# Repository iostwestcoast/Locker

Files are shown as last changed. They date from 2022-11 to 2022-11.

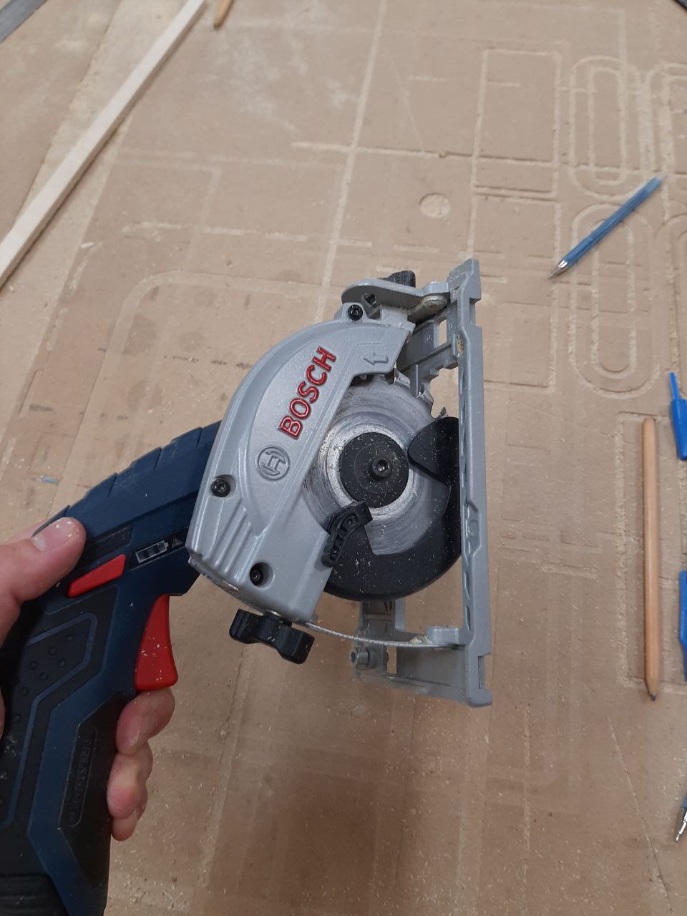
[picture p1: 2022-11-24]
Photos/photo_2022-11-24_02-31-51.jpg

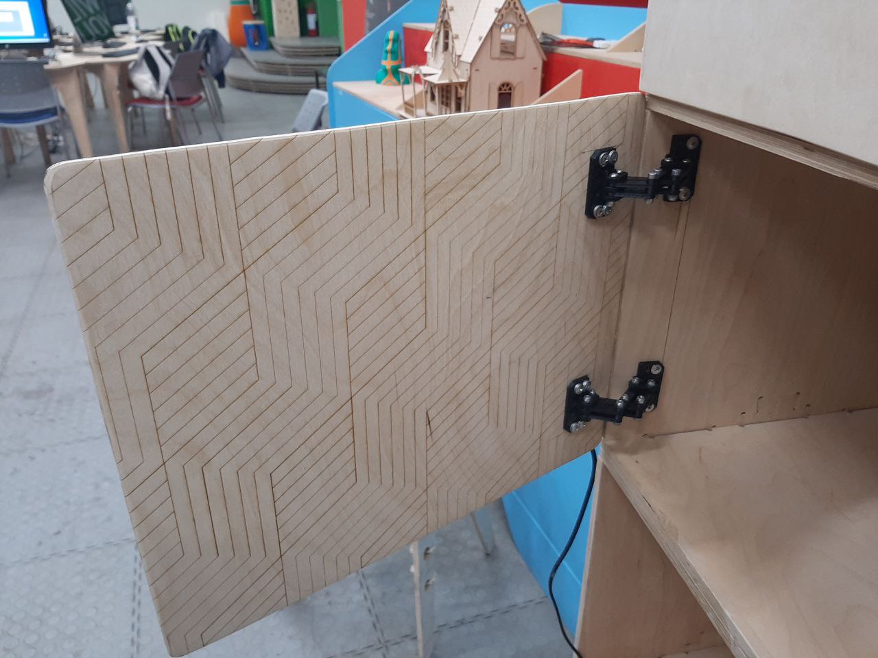
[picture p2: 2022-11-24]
Photos/photo_2022-11-24_02-32-20.jpg

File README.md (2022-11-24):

# Locker
Creating a locker door from plywood and fabricating with the assembly of the necessary equipment

## Production process

Marking and cutting out a plywood door 



Door assembly printing



## The result

Interior view



Exterior view 



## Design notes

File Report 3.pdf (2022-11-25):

Иост Евгений МТМО 22–3

### Введение в проект

Целью данной работы являлось создание дверцы шкафчика, с учетом изготовления

петлей и электронного запирающего механизма, срабатывающего при помощи RFID метки

через датчик на управляющей плате.

### Изготовление деталей

Изначально был передвижной шкаф с 8ю отсеками. Для начала были сняты

размеры проема для дверцы 445 мм на 355 мм. Было решено, что дверца будет сделана в

нахлест на рамки шкафчика. В качестве материала была выбрана фанера 6 мм, так как это

удобный в обработке и эксплуатации материал. Далее была произведена разметка на листе

фанеры и с помощью ручной мини циркулярной пилы была вырезана дверца.

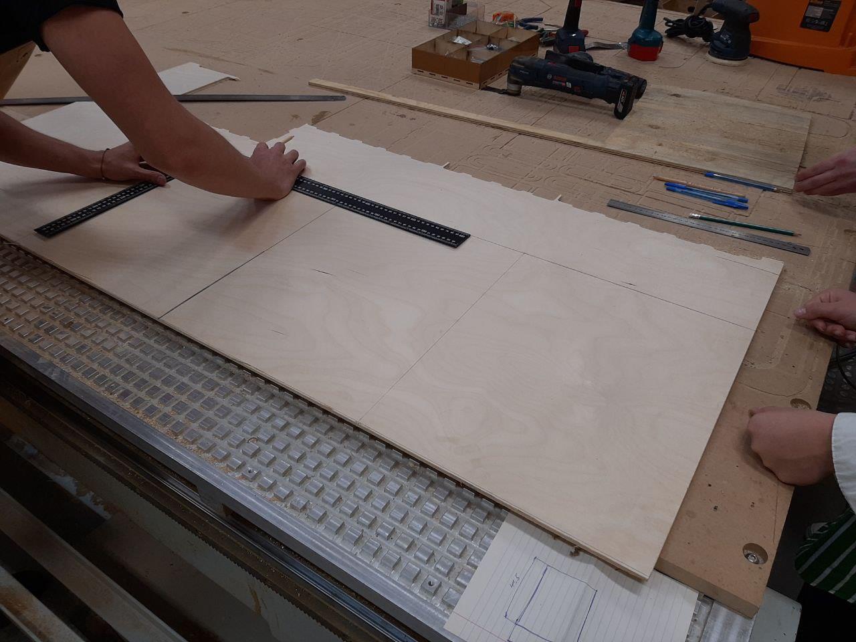
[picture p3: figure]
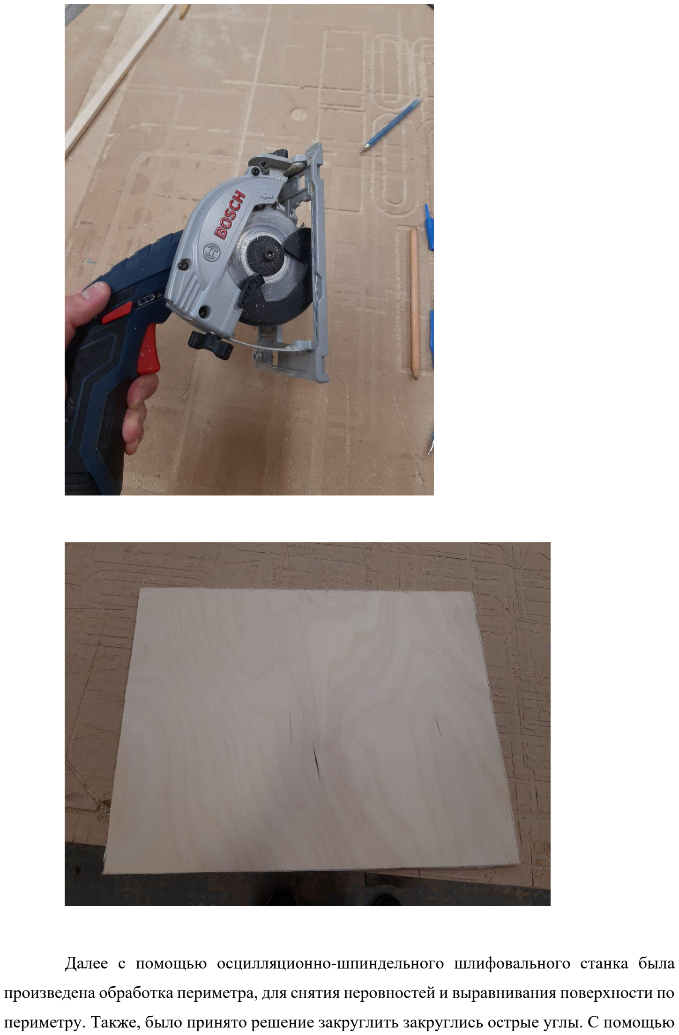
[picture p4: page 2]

Далее с помощью осцилляционно-шпиндельного шлифовального станка была

произведена обработка периметра, для снятия неровностей и выравнивания поверхности по

периметру. Также, было принято решение закруглить закруглись острые углы. С помощью

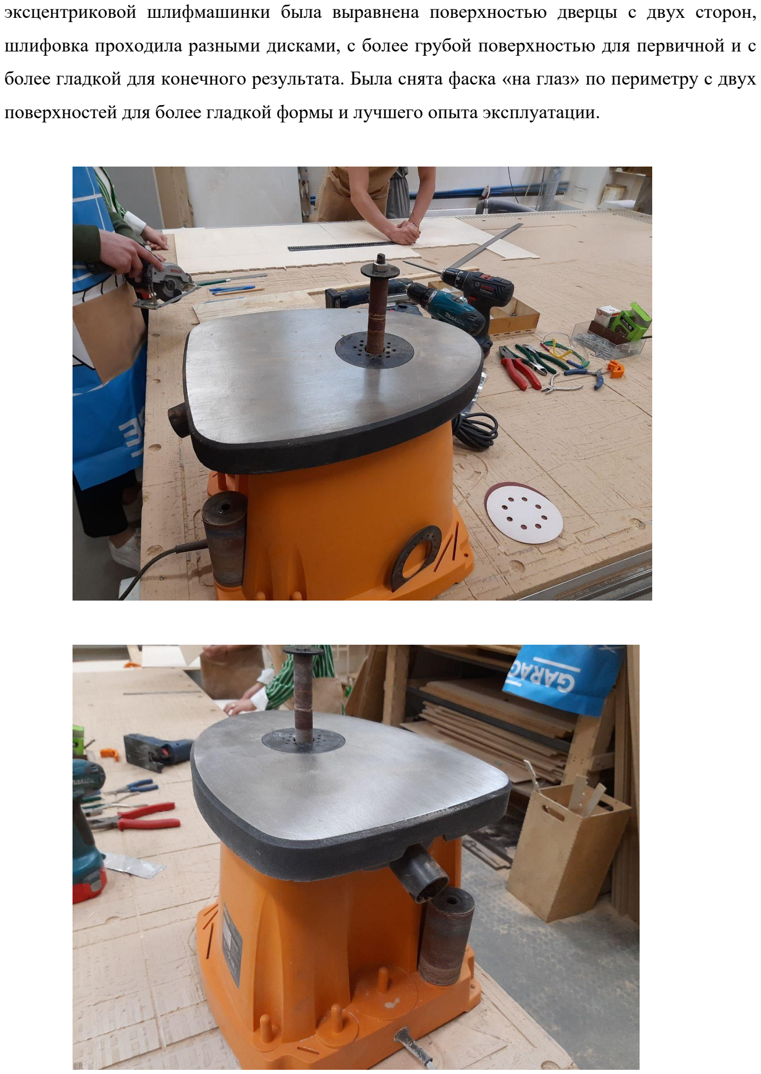
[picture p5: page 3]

эксцентриковой шлифмашинки была выравнена поверхностью дверцы с двух сторон,

шлифовка проходила разными дисками, с более грубой поверхностью для первичной и с

более гладкой для конечного результата. Была снята фаска «на глаз» по периметру с двух

поверхностей для более гладкой формы и лучшего опыта эксплуатации.

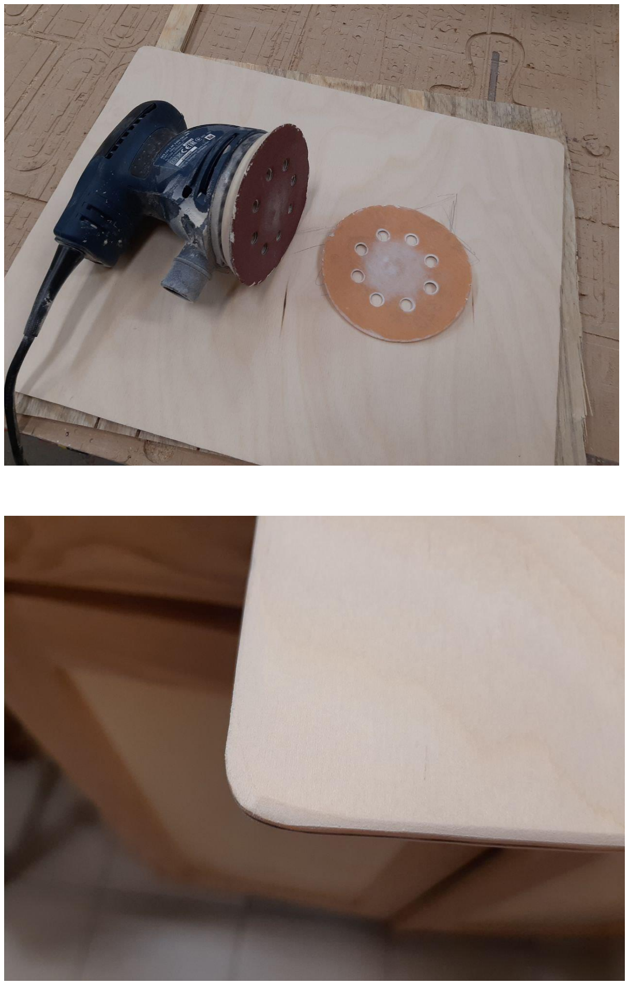
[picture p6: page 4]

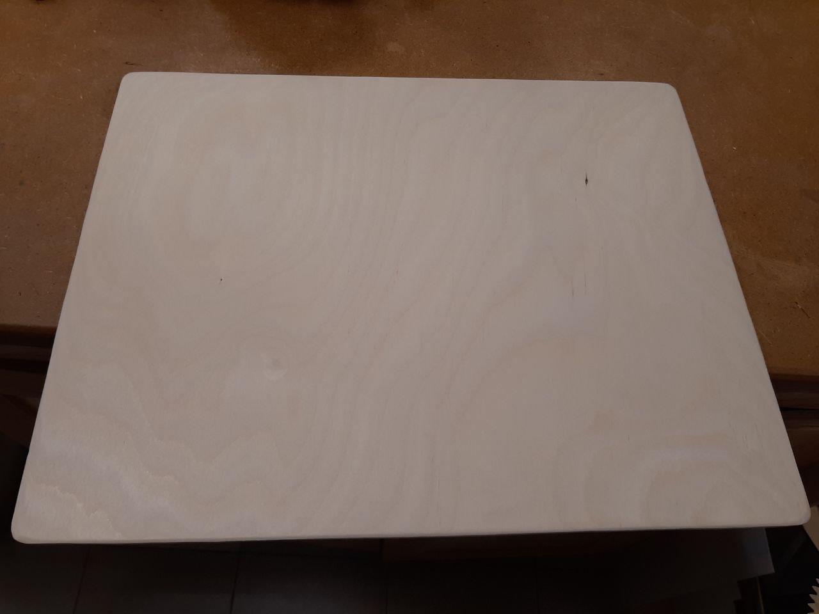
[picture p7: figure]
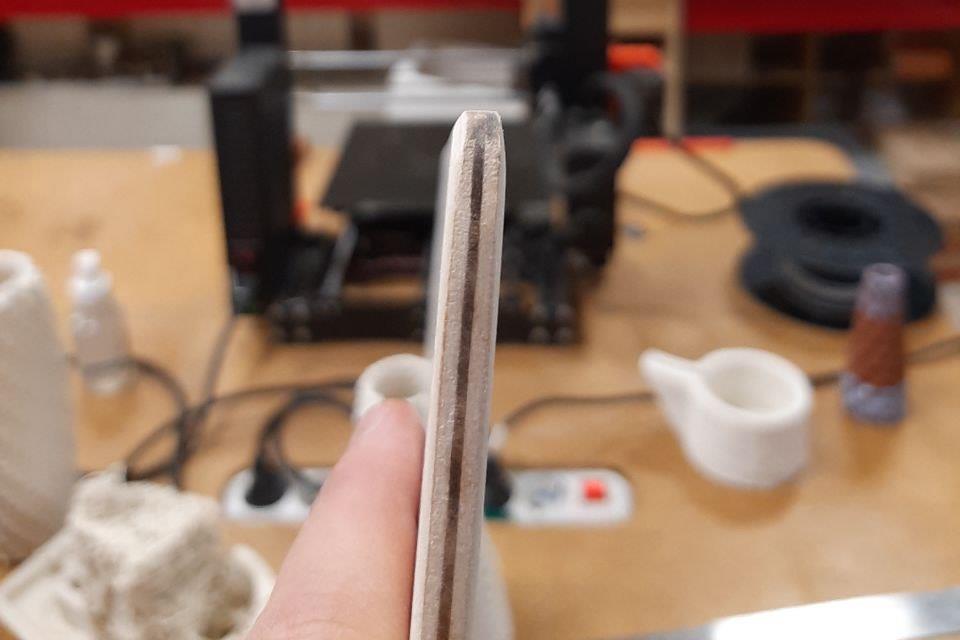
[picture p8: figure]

С обработкой поверхности было закончено. На следующем этапе работы был

выбран общий дизайн и расположение на дверце номера локера и именных данных. Для

начала были подобраны и протестированы настройки в программе для нанесения

гравировки на дверце. Была сделана гравировка номера и имени. Далее на листе плотной

бумаги был вырезан на лазерном станке трафарет цифры. Изначально гравировка номера

была сделана для точного расположения трафарета. Трафарет был закреплен

двухсторонним скотчем для лучшего прилегания. Вся дверца была закрыта листами, чтобы

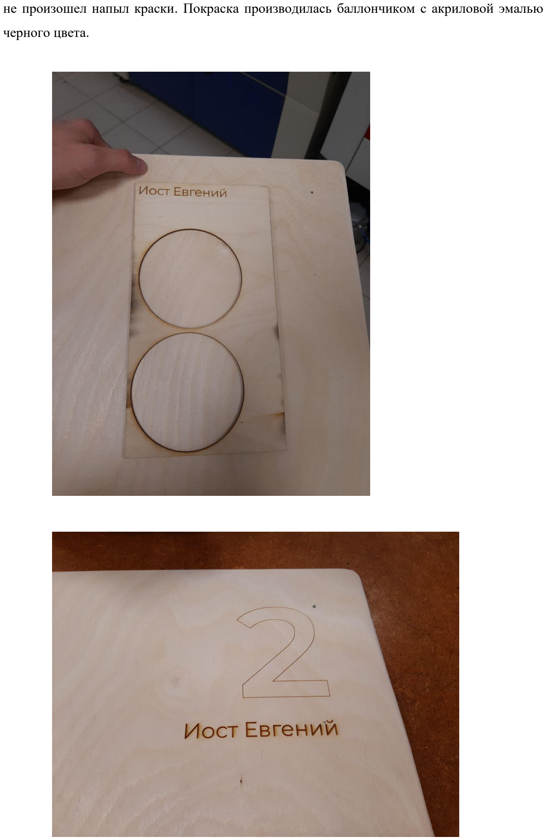
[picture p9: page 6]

не произошел напыл краски. Покраска производилась баллончиком с акриловой эмалью

черного цвета.

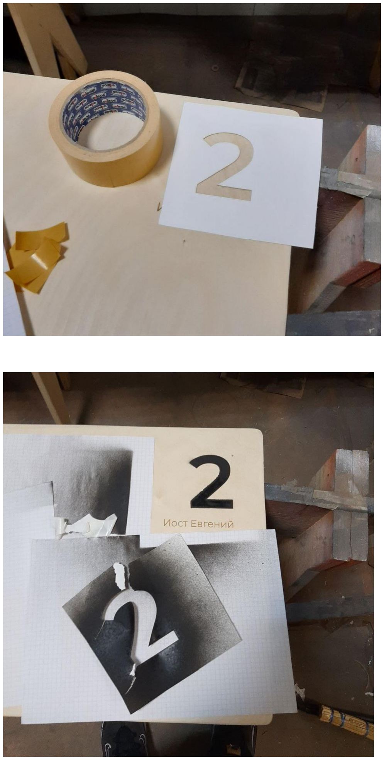
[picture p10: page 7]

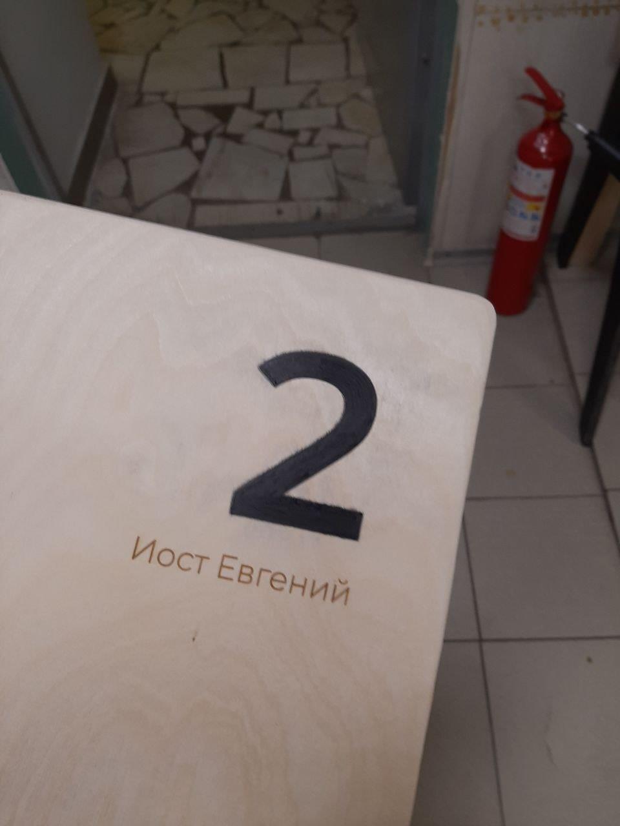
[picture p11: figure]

Что качается дизайна задней поверхности, было принято решение сделать

гравировку. Была найдена картинка в векторном изображении и была произведена

гравировка на весь периметр задней поверхности.

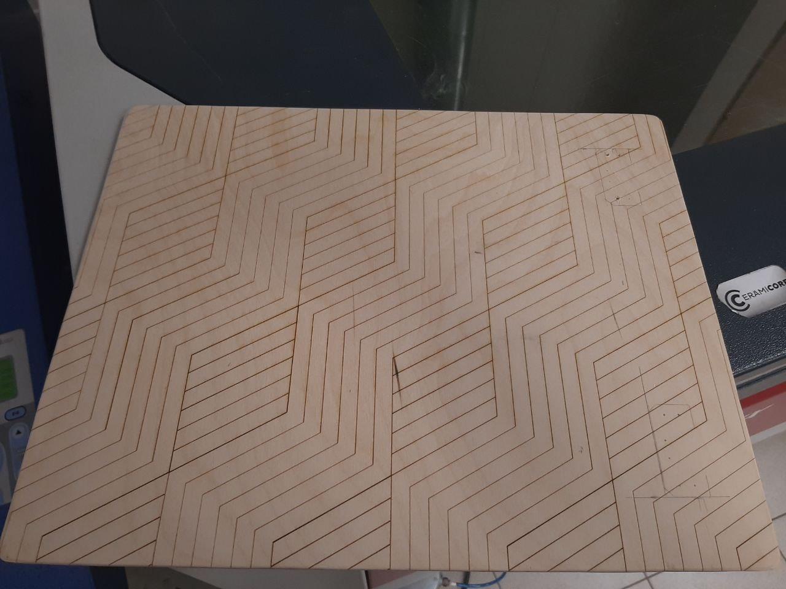
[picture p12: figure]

На следующем этапе работы было изготовление петель. Трудность была в том, что

нужны были петли с выносом в 1 и более см, так как дверца должна располагаться внахлест.

Изготовление было принято решение производить при помощи 3д принтера по пластику.

Изначально была найдена модель петель, которые печаталась бы сразу в сборе, но сколько

разных пластиков или настроек печати не было бы поменяно, деталь всегда получалась с

дефектами: заблокированные подвижные элементы, низкая прочность детали, сильные

люфты в соединениях. Далее была найдена более совершенная модель петель, но они были

сборочные с использованием болтов м6. Они были напечатаны и собраны во едино.

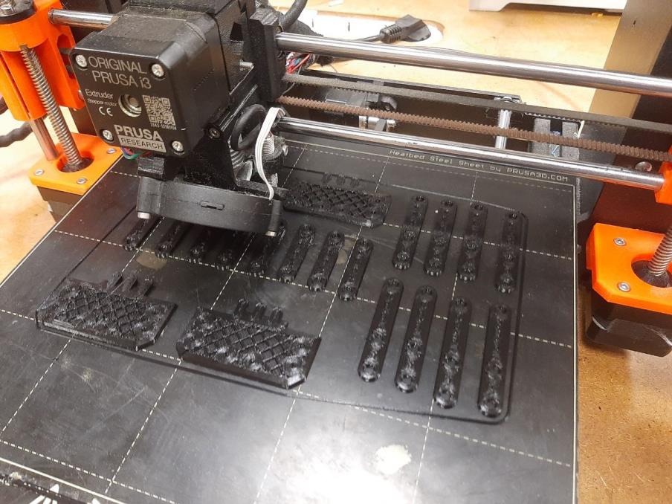
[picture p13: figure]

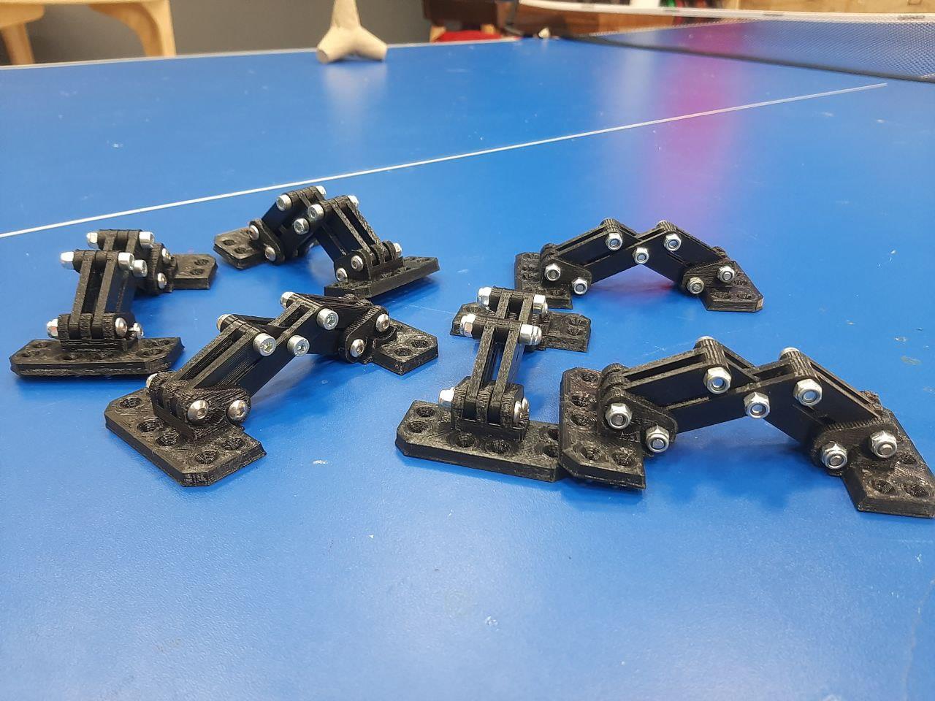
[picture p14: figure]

Поскольку локер с электронным запирающим механизмом, а в качестве его был

выбран соленоид, для его фиксации и работоспособности механизма было распечатано

дополнительно навесное оборудование: крепление соленоида, язычек, паз для язычка и

фиксатор рабочей втулки соленоида. Из-за того, что данные компоненты тоже были

напечатаны, они нуждались в доработке, отрезались выступающие, дефектные части

первых слоев печати, производилась шлифовка рабочих скользящих поверхностей до

более-менее гладкого состояния. Таже из-за несовершенства печати, рассверливались

отверстия для крепления петель, крепления и паза на дверцу шкафчика. Далее была сделана

сборка компонентов, крепление прикручивалось короткими болтами м3, цианоакрилатным

клеем приклеен фиксатор втулки для лучшей фиксации, язычек приклеен на клеевой

пистолет. Также на данным этапе было измерено расстояние с запасом от соленоида до

основного блока управления всеми локерами с учетом кабель менеджмента для напайки

проводов к соленоиду. Дале провода были припаяны, а места спайки заизолированы

термоусадкой, провода закручивались для лучшего менеджмента и эстетичного вида.

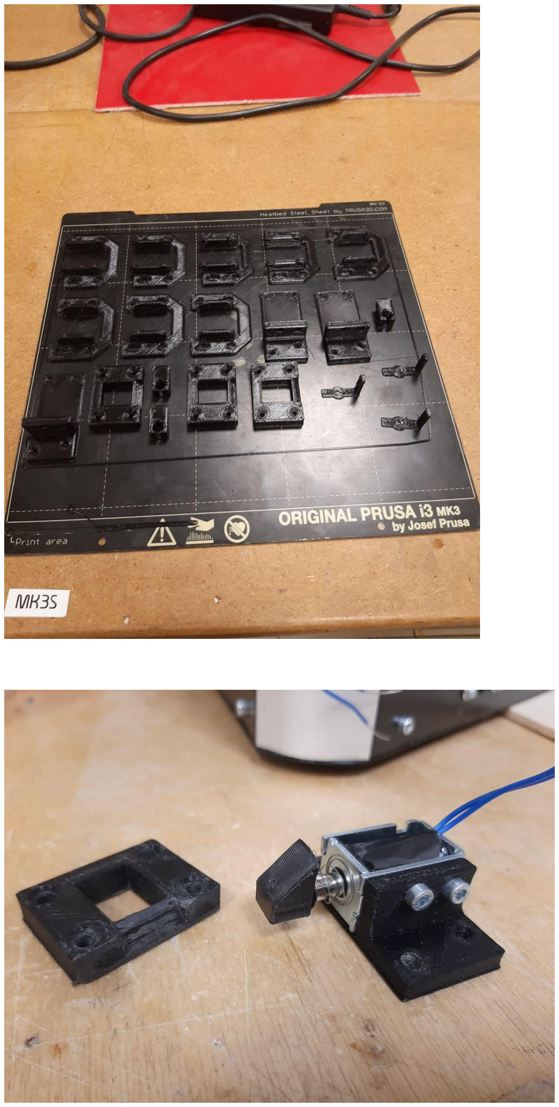
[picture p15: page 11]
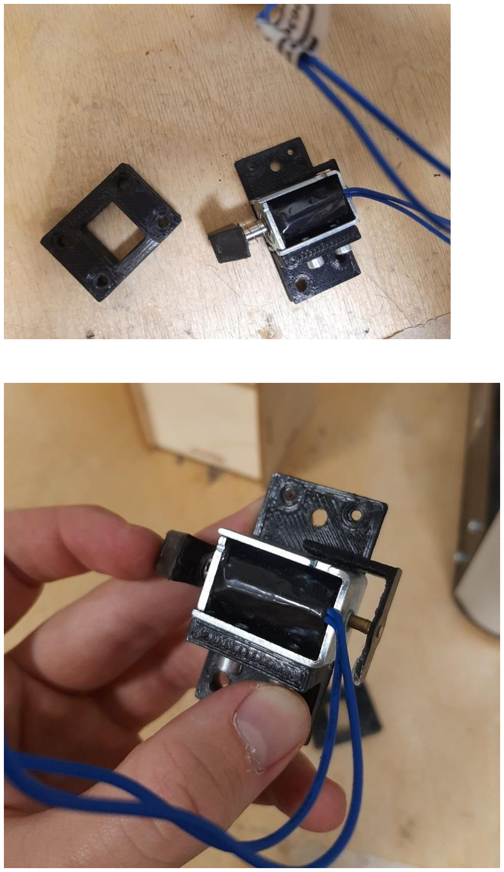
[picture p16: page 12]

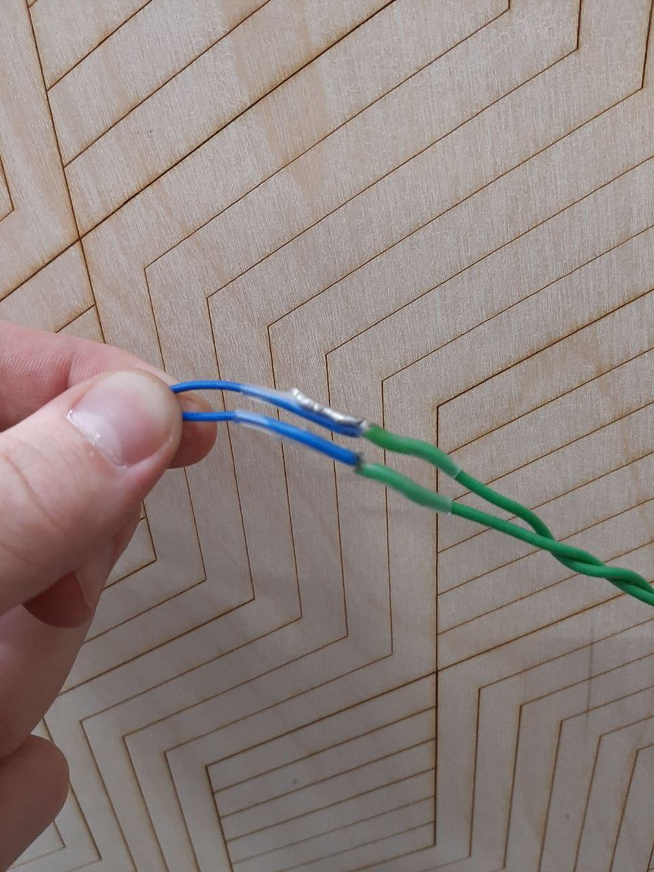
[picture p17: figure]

Механизм локера будет отрываться с помощью RFID метки, которую мы подносим

к датчику-считывателю в основном блоке управления. Для метки было принято решение

сделать брелок для ключей, а метка имеется на самоклеящийся основе. Для проекта было

найдено большое разнообразие брелков. Выбрав лучший вариант, модель была подогнана

по размерам к метке и брелок был напечатан на принтере в черном цвете, далее вклеена

метка.

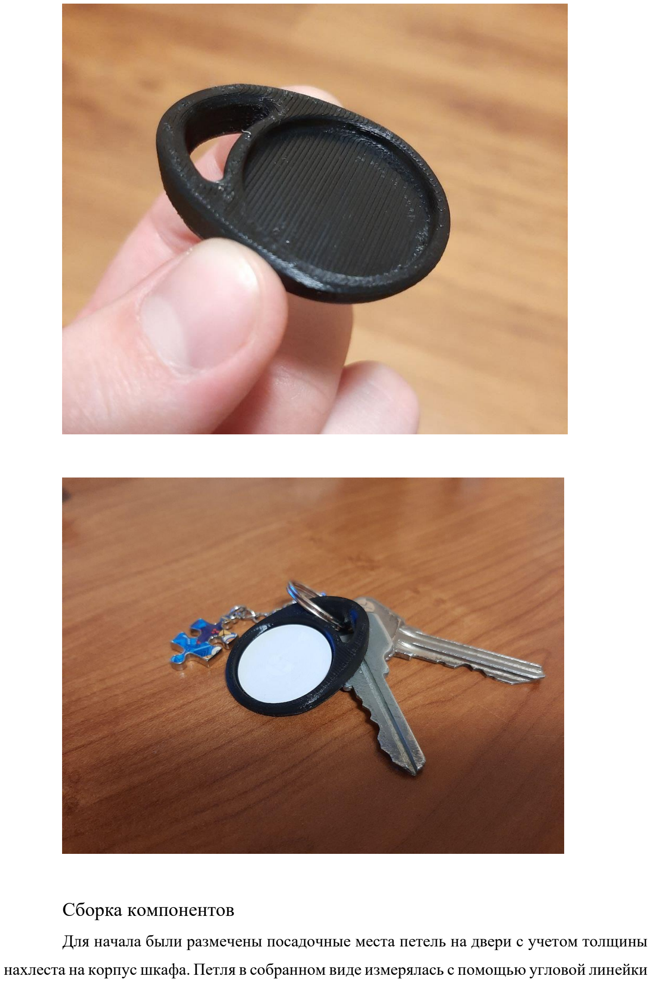
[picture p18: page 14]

### Сборка компонентов

Для начала были размечены посадочные места петель на двери с учетом толщины

нахлеста на корпус шкафа. Петля в собранном виде измерялась с помощью угловой линейки в закрытом виде, отступ от края дверцы составил 6 см, а от края шкафа 5 см. Так как фанера

толщиной всего 6 мм, а необходимых саморезов не было в наличии для работы над

проектом, пришлось опытным путем и методом проб и замеров подбирать количество шайб

для проставки между шляпкой прессшайбы, также пришлось укорачивать острый

наконечник пресшайбы кусачками. Когда петли были прикручены к двери, произвелась

разметка на шкафу. Далее прикручена дверца. Косательно запирающего механизма также

была произведена разметка и с помощью проставок шайбами весь механизм был

прикручен, включая паз для языка. Кабель менеджмент был сделан с помощью медельного

степлера с короткими скобами. Также кабель питания соленоида был протянут и подключен

в плату управления на нужную позицию по номеру локера.

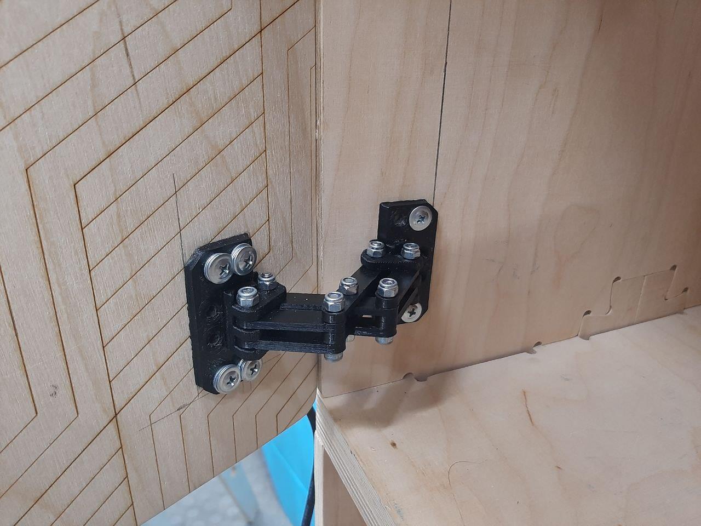
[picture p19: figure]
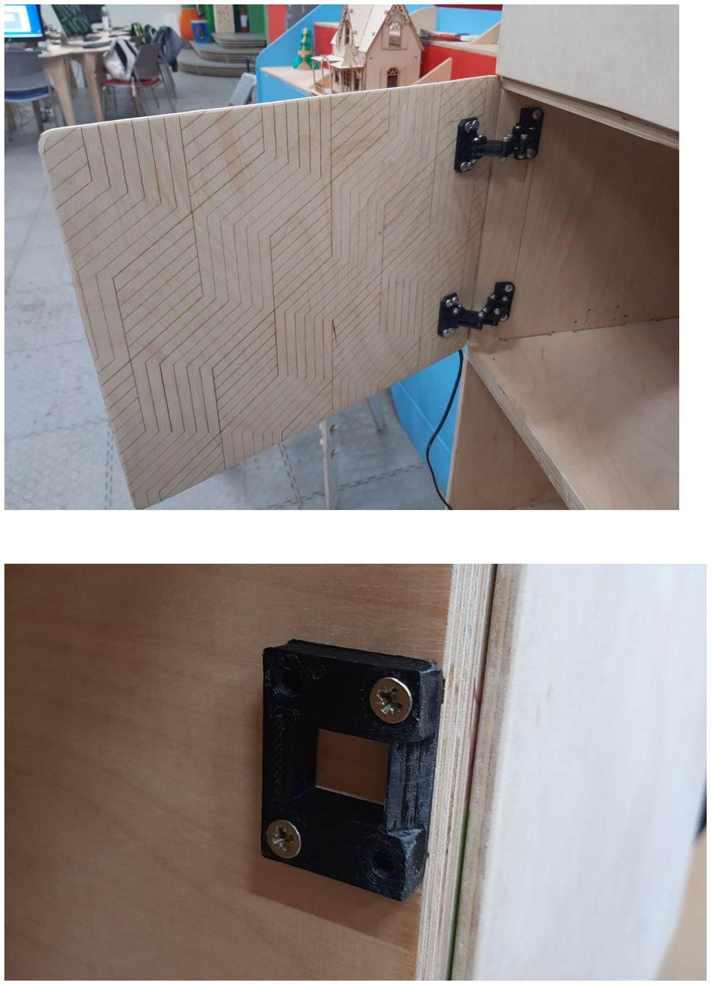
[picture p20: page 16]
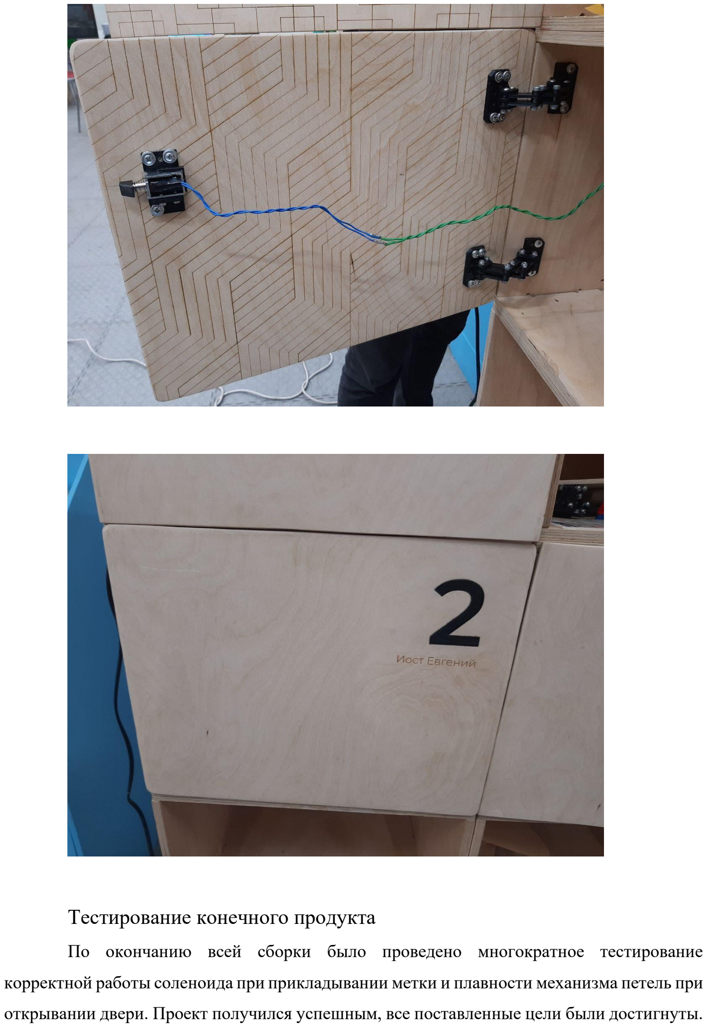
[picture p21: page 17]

### Тестирование конечного продукта

По окончанию всей сборки было проведено многократное тестирование

корректной работы соленоида при прикладывании метки и плавности механизма петель при

открывании двери. Проект получился успешным, все поставленные цели были достигнуты.

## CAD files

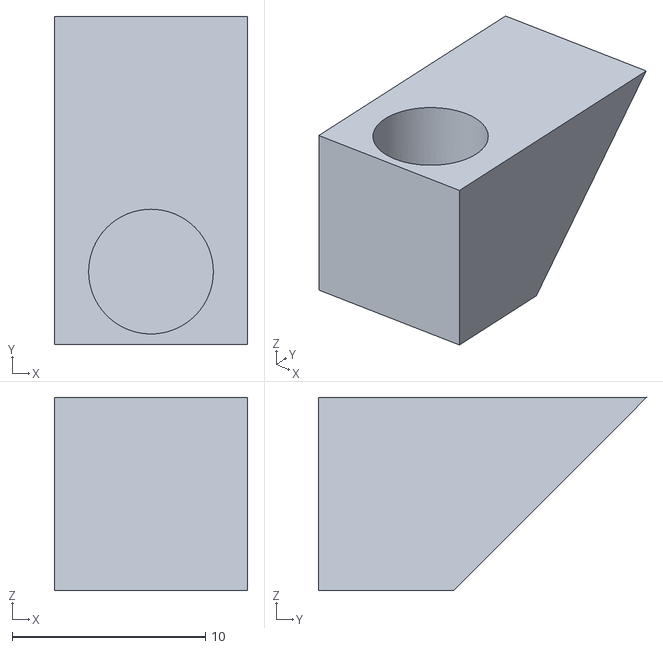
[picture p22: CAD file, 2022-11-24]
Files/Bodykit on solenoid/solenoid_tongue.stl
10.0 x 17.0 x 10.00

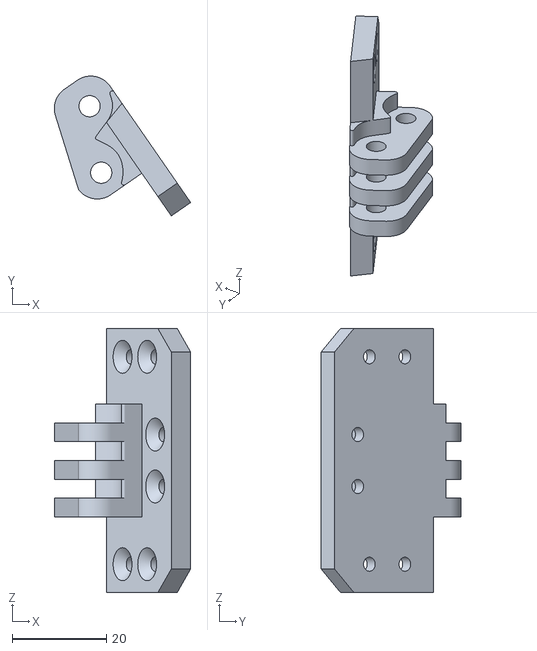
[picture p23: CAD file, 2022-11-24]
Files/Door hinge assembly/Hinge_bracket_2_-_left_1x.stl
28.9 x 29.7 x 56.0

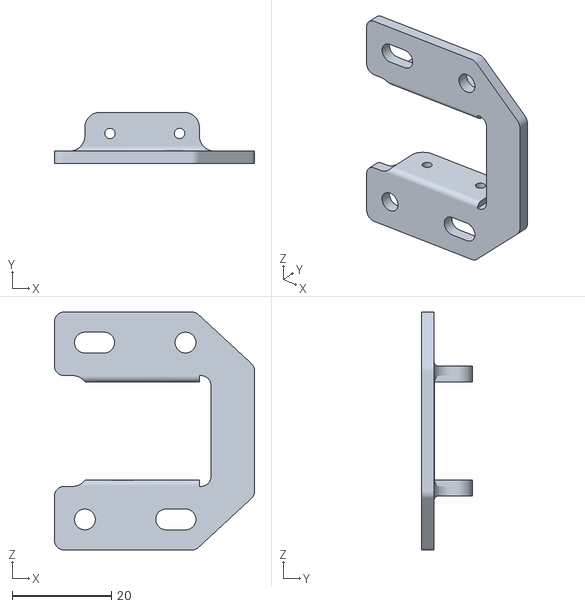
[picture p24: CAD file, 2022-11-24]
Files/Door hinge/Base_Frame_Side_v2.STL
40.4 x 10.3 x 48.0

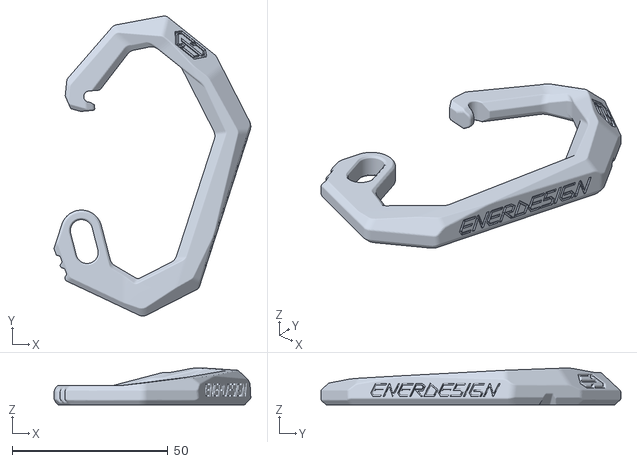
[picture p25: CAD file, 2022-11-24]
Files/Rfid key fob/1/DH010.STL
63.1 x 96.3 x 11.8

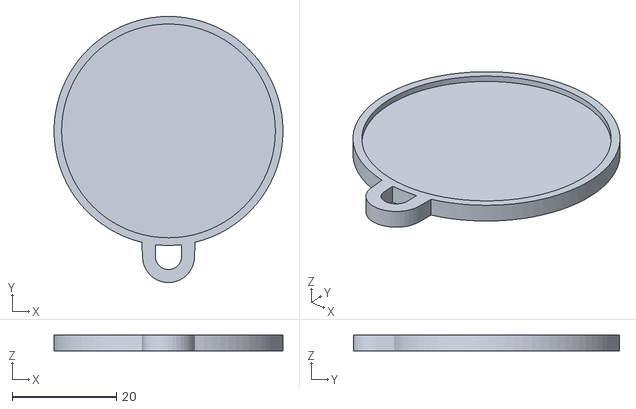
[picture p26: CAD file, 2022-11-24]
Files/Rfid key fob/2/AmiiboCoin.stl
44.0 x 51.1 x 3.00

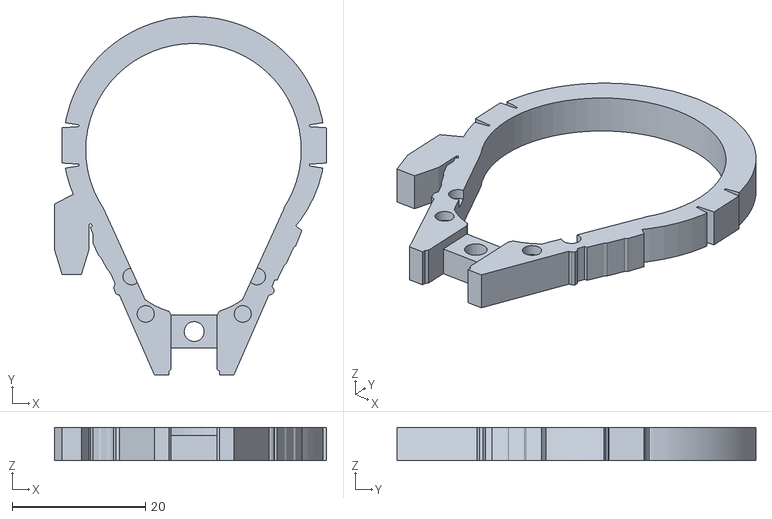
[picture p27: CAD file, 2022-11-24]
Files/Rfid key fob/3/MILFALCON_1.stl
40.9 x 53.9 x 5.00

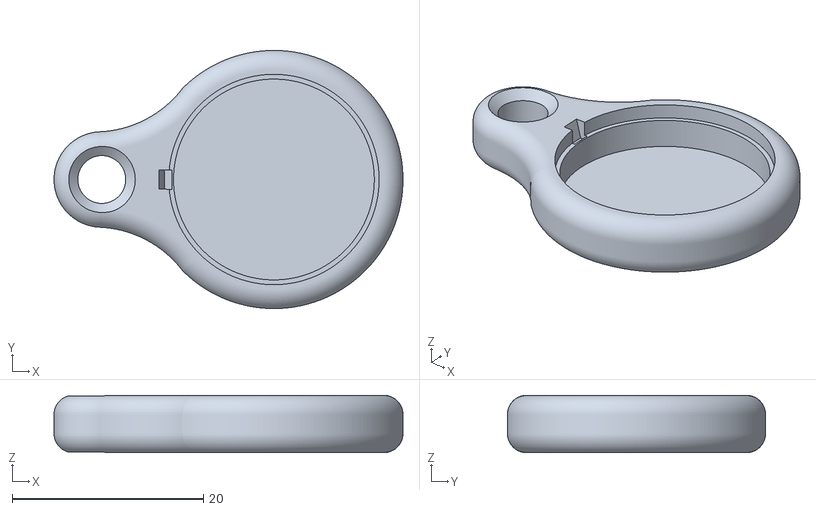
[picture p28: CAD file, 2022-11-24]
Files/Rfid key fob/4/Body2.stl
36.5 x 27.0 x 6.00

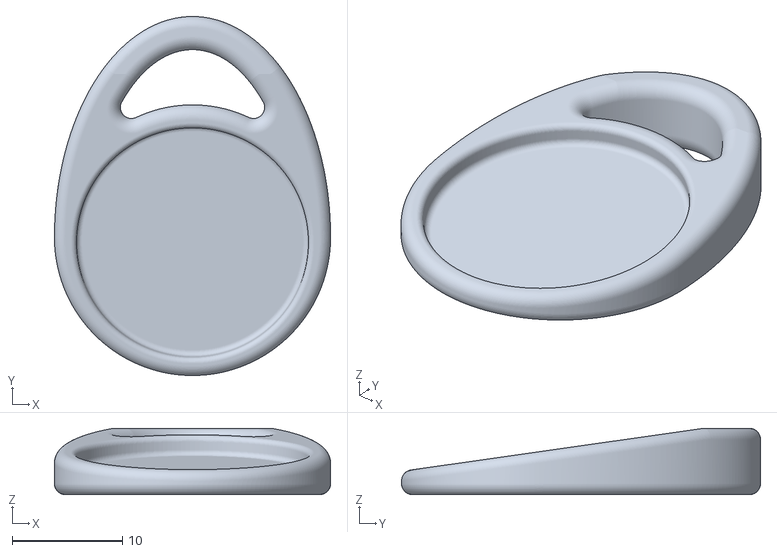
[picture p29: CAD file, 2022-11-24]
Files/Rfid key fob/5/Flat_RFID_disc_fob_mk2_v7_smiley_hole_v1.stl
25.0 x 32.5 x 6.00

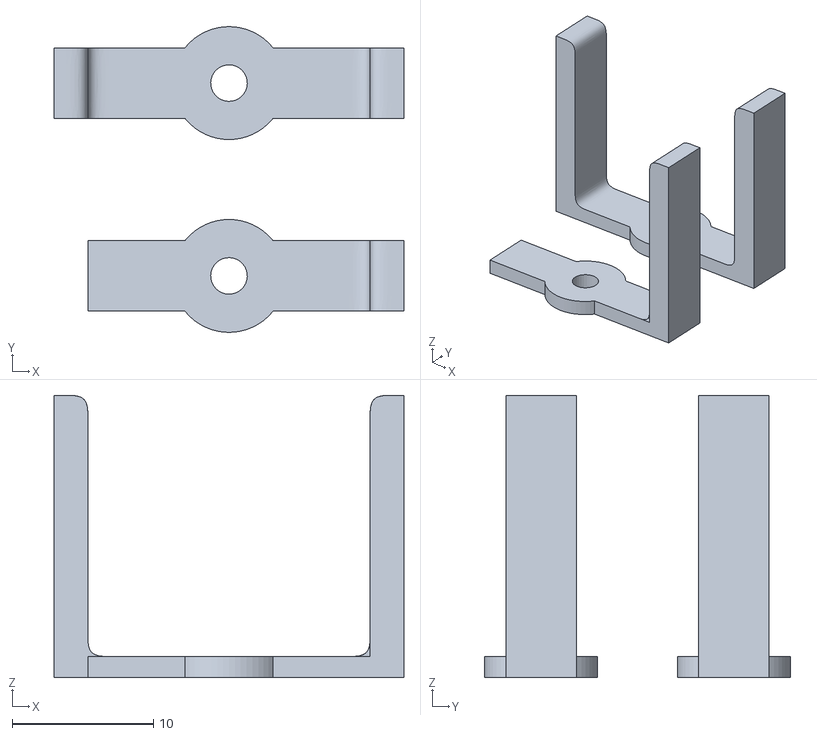
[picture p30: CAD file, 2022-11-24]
Files/Bodykit on solenoid/lock_blocker_w_aligner.stl
24.8 x 21.7 x 20.0

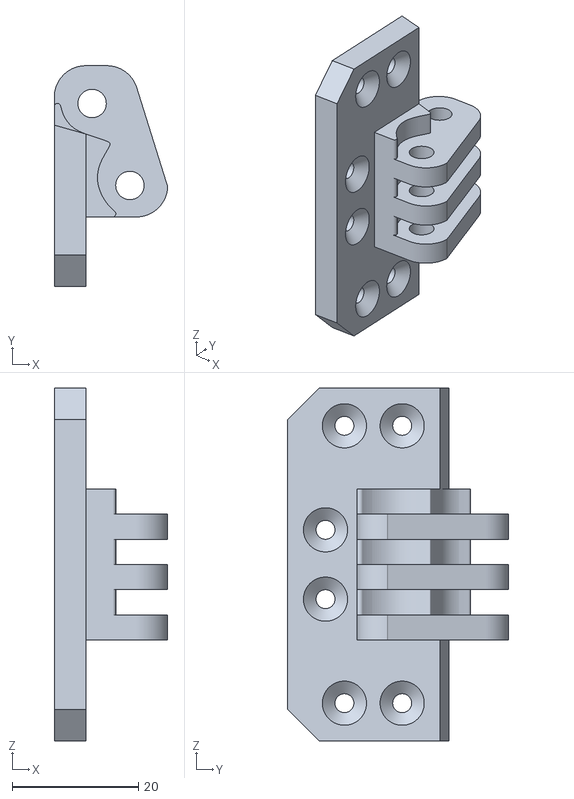
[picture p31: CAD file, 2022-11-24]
Files/Door hinge assembly/Hinge_bracket_2_-_right_1x.stl
18.0 x 35.0 x 56.0

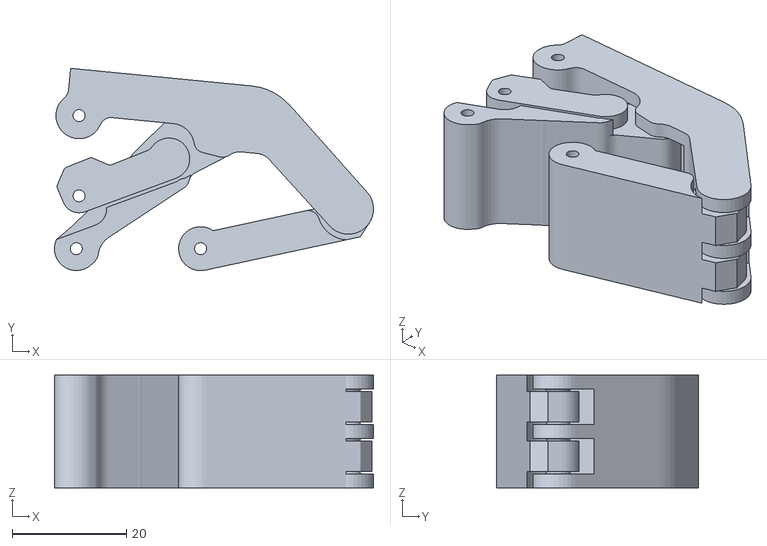
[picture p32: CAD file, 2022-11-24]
Files/Door hinge/Articulating_Hinge_v2_ReductionofOverHangs.STL
55.8 x 35.4 x 19.7

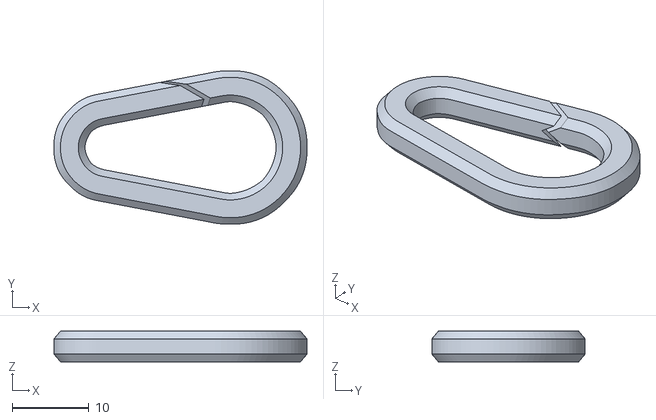
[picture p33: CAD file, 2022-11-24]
Files/Rfid key fob/1/customcarabiner_20200427-66-1wkannb.stl
33.0 x 20.0 x 4.00

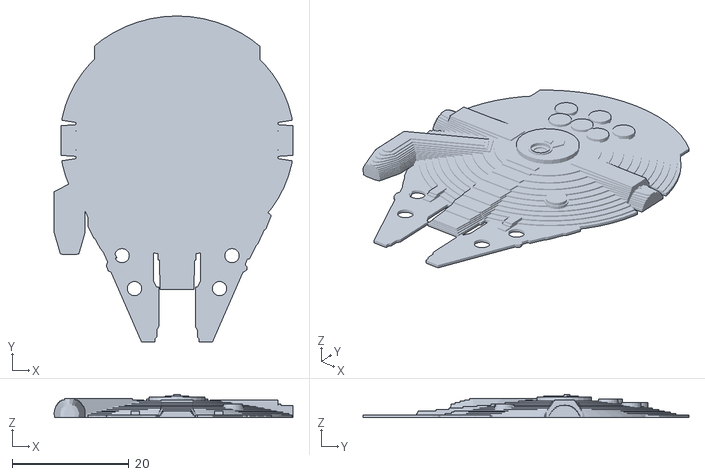
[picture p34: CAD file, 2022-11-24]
Files/Rfid key fob/3/MILFALCON_3.stl
40.9 x 55.8 x 3.96

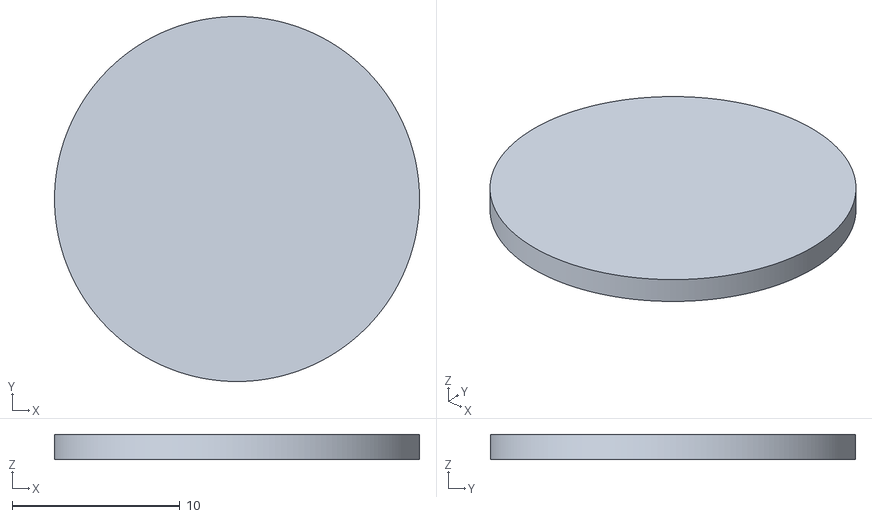
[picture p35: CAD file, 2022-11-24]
Files/Rfid key fob/4/Cap.stl
21.7 x 21.7 x 1.50

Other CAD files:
Files/Bodykit on solenoid/solenoid_endstop.stl
Files/Door hinge assembly/Hinge_arm_-_long_6x.stl
Files/Door hinge/Base_Door_Side_v2.STL
Files/Rfid key fob/1/DD007.STL
Files/Bodykit on solenoid/solenoid_holder.stl
Files/Door hinge assembly/Hinge_arm_-_short_6x.stl
Files/Door hinge/Articulating_Hinge_v2.3mf
Files/Door hinge/Articulating_Hinge_v2.STL
Files/Door hinge/Articulating_Hinge_v2_scaled.stl
Files/Door hinge/SurfaceHinge.STEP
Files/Rfid key fob/3/MILFALCON_2.stl
